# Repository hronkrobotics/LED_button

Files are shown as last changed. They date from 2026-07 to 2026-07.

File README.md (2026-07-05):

# LED Button

## Project Overview

This repository documents a modular ESP32-based LED button controller designed for rapid prototyping, debugging, and community experimentation. The project combines a custom PCB, modular JST-XH wiring, an OLED display, an 8x8 addressable LED matrix, mechanical switches, and a portable battery system into a compact handheld device.

The firmware in this repository remains the primary functional layer. This repository now adds the engineering documentation, mechanical references, PCB files, manufacturing notes, and assembly guidance required to build, service, and improve the hardware.

This platform is currently being used primarily as a VEX IQ STEM education curriculum asset, where it serves as an engaging hands-on tool for teaching timing, reaction, and interactive electronics concepts. It is also designed to be expandable into many other use cases, including outreach demonstrations, classroom competitions, prototyping platforms, and future connected or networked interactive systems.

## Demonstration Videos

These square-cropped demo clips are embedded directly in the README so they can play in the browser. The original source recordings are also preserved in [media/led-button-timer.mov](media/led-button-timer.mov) and [media/led-button-interface.mov](media/led-button-interface.mov).

### Timer mode
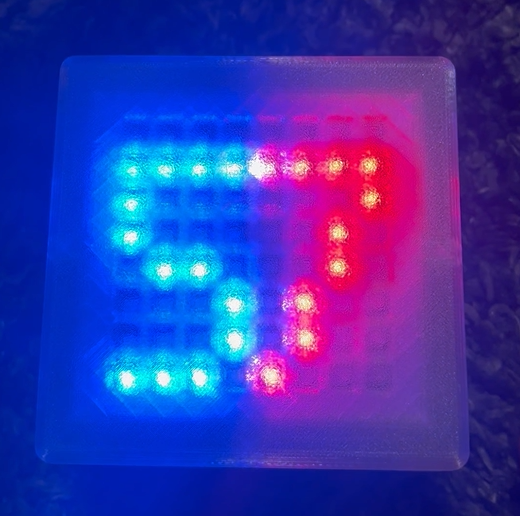
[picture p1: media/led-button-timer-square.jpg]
Timer mode preview


### Button mode
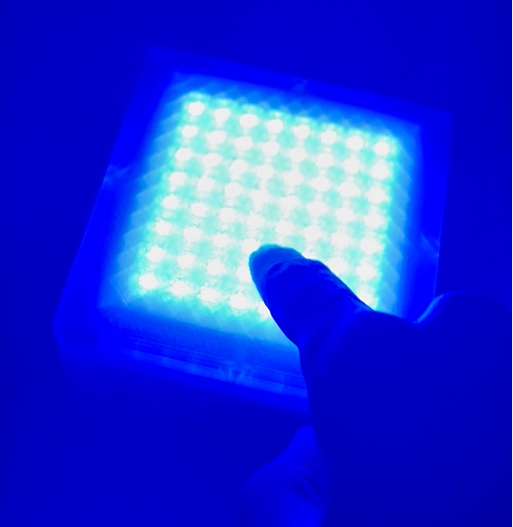
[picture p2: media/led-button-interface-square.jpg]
Button mode preview


## Features

- ESP32-based control platform
- 1.3-inch SH1106 OLED display
- 8x8 flexible WS2812B-compatible LED matrix
- Four Cherry MX Blue switches for primary input
- Two auxiliary momentary pushbuttons
- Passive piezo buzzer for audio feedback
- Dual 18650 battery system with external charging module
- Modular JST-XH connector architecture for easy assembly and replacement
- Firmware support for timer and reaction-style game modes

## Future UI and Connectivity Enhancements

Planned improvements for the next hardware and firmware iteration include:

- Wi-Fi connectivity for configuration, telemetry, and remote updates
- BLE support for phone or tablet pairing and control
- Multi-button serial connection for linking multiple units into a shared interactive setup

## Hardware Specifications

- Main controller: ESP32-WROOM-32
- Display: SH1106 OLED, 128x64
- LED matrix: 8x8 addressable LED panel
- Input: 4x Cherry MX Blue switches, 2x auxiliary buttons
- Power: 2x 18650 cells in a dual-cell holder/shield
- Charging: USB-C via external extension and battery shield
- Enclosure: 3D-printed housing with PCB standoffs and switch mounts

## Repository Structure

- [firmware](firmware/): firmware source and build assets
- [hardware](hardware/): PCB, CAD, manufacturing, and drawing files
- [docs](docs/): assembly, electronics, firmware, manufacturing, and add-on documentation
- [BOM](BOM/): bill of materials files and supporting documents

## Required Tools

- Arduino IDE or PlatformIO
- USB cable for firmware flashing
- Soldering iron and solder
- JST-XH crimping or soldering tools
- Hex drivers, screwdrivers, wire strippers, and flush cutters
- Multimeter for continuity and power testing

## Flashing Firmware

1. Open the firmware source in [firmware/LED_button.ino](firmware/LED_button.ino).
2. Select the appropriate ESP32 board profile in your toolchain.
3. Compile and upload the sketch.
4. Verify OLED initialization, button response, and LED output.

## Manufacturing and Assembly

See [docs/manufacturing/manufacturing-guide.md](docs/manufacturing/manufacturing-guide.md) for build instructions and [docs/assembly/assembly-guide.md](docs/assembly/assembly-guide.md) for mechanical assembly steps.

## License

This project is released under the MIT License. See [LICENSE](LICENSE) for details.

## Credits

- Firmware and prototype development: HRONK Robotics
- Hardware documentation and repository organization: HRONK Robotics
- Mechanical and electronic design references: included project files in this repository
- Wall-mount accessory reference: [hardware/cad/LED_BUTTON_VEX_WALL_MOUNT_3D_FILES.step](hardware/cad/LED_BUTTON_VEX_WALL_MOUNT_3D_FILES.step)

<!-- Add CAD renders, exploded views, and photographs here later -->

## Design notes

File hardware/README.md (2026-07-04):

# Hardware Overview

This folder stores the physical design assets for the LED button controller.

## Contents

- [pcb](pcb/): PCB schematic, manufacturing outputs, and connector information
- [cad](cad/): STEP files for the mechanical assemblies and enclosure components
- [stl](stl/): STL output location for printable parts
- [manufacturing](manufacturing/): build and fabrication notes
- [drawings](drawings/): drawing placeholders for future mechanical and assembly documentation

## Design Intent

The hardware revision documented here is a modular prototype platform. It prioritizes flexibility, serviceability, and rapid iteration over production optimization. The design intentionally uses an ESP32 development board, an external battery shield, and JST-XH wiring to simplify debugging and part replacement.

## Hardware Architecture

```mermaid
flowchart LR
    A[Battery pack] --> B[Battery shield / charger]
    B --> C[Power distribution]
    C --> D[ESP32 controller]
    C --> E[OLED display]
    C --> F[LED matrix]
    C --> G[Input buttons]
    C --> H[Buzzer]
    D --> E
    D --> F
    D --> G
    D --> H
```

This layout is chosen because it keeps the device portable and easy to service while still making the PCB the main integration point for the system. The split between modular subsystems and the custom PCB allows future revisions to improve manufacturing density without discarding the existing functional architecture.

## Included Files

- [pcb/LED_Button_PCB_Schematic.pdf](pcb/LED_Button_PCB_Schematic.pdf)
- [pcb/Gerber_LED_BUTTON_2026-07-04.zip](pcb/Gerber_LED_BUTTON_2026-07-04.zip)
- [cad/LED_BUTTON_3DFILES.step](cad/LED_BUTTON_3DFILES.step)
- [cad/LED_BUTTON_VEX_WALL_MOUNT_3D_FILES.step](cad/LED_BUTTON_VEX_WALL_MOUNT_3D_FILES.step)

<!-- Add CAD render or assembly photo here -->

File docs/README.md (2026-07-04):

# Documentation Index

This directory contains the engineering documentation for the LED button project.

## Documents

- [Assembly Guide](assembly/assembly-guide.md)
- [Electronics Overview](electronics/overview.md)
- [Firmware Overview](firmware/overview.md)
- [Manufacturing Guide](manufacturing/manufacturing-guide.md)
- [Add-ons](addons/walnut-addon.md)

The assembly workflow is documented as a single integrated assembly guide rather than separate mechanical and assembly documents.

## Related Resources

- [../README.md](../README.md)
- [../hardware/README.md](../hardware/README.md)
- [../BOM/README.md](../BOM/README.md)

<!-- Add system-level diagram or exploded view later -->

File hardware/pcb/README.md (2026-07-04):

# PCB Documentation

## Purpose

The custom PCB acts as the central interconnect platform for the LED button controller. It provides mechanical support for the ESP32 development board and routes power, ground, and GPIO signals to the OLED display, LED matrix, buttons, buzzer, and battery system.

## Design Notes

- The PCB is designed around modular JST-XH connectors.
- Power and ground are distributed to all subsystems through the PCB.
- The ESP32 development board is mounted as a removable module.
- The board is intended for debugging, prototype assembly, and easy maintenance.

## Key Interfaces

- OLED: I2C interface via JST connector
- LED matrix: single data line plus power and ground
- Switches: input lines with pull-ups in firmware
- Buzzer: PWM or simple digital output
- Battery shield: regulated 5 V power input

## Reference Files

- [LED_Button_PCB_Schematic.pdf](LED_Button_PCB_Schematic.pdf)
- [Gerber_LED_BUTTON_2026-07-04.zip](Gerber_LED_BUTTON_2026-07-04.zip)

## Placeholder Notes

- Connector pinout table to be expanded from the schematic once the final revision is verified.
- GPIO allocation table to be linked to the firmware mapping in [../docs/firmware/overview.md](../docs/firmware/overview.md).

<!-- Add PCB layout image or fabrication drawing here -->

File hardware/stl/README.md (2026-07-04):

# STL Files

This directory is reserved for exported STL files for the printable parts of the enclosure and accessories.

The current repository contains the source STEP files in [../cad](../cad). STL exports should be added here once prepared for fabrication.

<!-- Add STL exports and print notes here -->

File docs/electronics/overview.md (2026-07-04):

# Electronics Overview

## Hardware Architecture

The hardware is organized as a modular embedded system where power, sensing, actuation, and user interface functions are split into distinct blocks that connect through the custom PCB and JST-XH wiring.

```mermaid
flowchart LR
    A[2x 18650 cells] --> B[Battery shield / charger]
    B --> C[Regulated 5V rail]
    C --> D[ESP32-WROOM-32]
    C --> E[SH1106 OLED display]
    C --> F[8x8 LED matrix]
    C --> G[Cherry MX buttons]
    C --> H[Auxiliary buttons]
    C --> I[Passive buzzer]
    D --> E
    D --> F
    D --> G
    D --> H
    D --> I
    D --> J[Custom PCB + JST-XH connectors]
```

### Why These Design Choices Work

The hardware architecture favors rapid iteration and serviceability over maximum miniaturization:

- The ESP32 and battery shield are used as modular building blocks so the prototype can be reworked quickly.
- JST-XH connectors simplify assembly, debugging, and replacement of displays, LEDs, buttons, and power connections.
- The custom PCB centralizes the wiring and keeps the prototype easier to manufacture and test than a loose breadboard layout.
- The separate battery pack and charging path make the device portable without forcing the electronics to be permanently sealed into the enclosure.

## Main Components

### ESP32-WROOM-32
The ESP32 is the main controller for the device. It handles UI rendering, button scanning, LED animation, buzzer output, and high-level game logic.

### SH1106 OLED Display
The OLED display provides status information, menus, battery and mode information, and simple user feedback. It is connected over a 4-wire JST-XH interface using VCC, GND, SDA, and SCL.

### Flexible 8x8 LED Matrix
The LED matrix is used for visual output such as games, animations, and status cues. It is connected through a 3-wire JST-XH connector carrying 5 V, GND, and a single data line.

### Dual 18650 Battery System
The portable power source consists of two 18650 cells mounted in a battery holder or shield. The system powers the ESP32 and peripherals through a regulated 5 V output from the battery shield.

### Battery Shield and Charging
The battery shield serves as the power-management module. It provides battery charging, protection, and regulated output. The USB-C extension allows charging without opening the enclosure.

### Cherry MX Switches
The four Cherry MX Blue switches are the main input devices. Each switch interfaces as a simple active-low input to the ESP32. Firmware uses internal pull-ups.

### Auxiliary Pushbuttons
The two auxiliary momentary buttons are used for system functions such as start, select, reset, or mode switching.

### Passive Buzzer
The passive buzzer provides simple audio feedback for button presses, mode changes, game events, and alarms. The firmware drives it with PWM or timed tone output.

### Custom PCB
The PCB serves as the interconnect backbone for the entire device. It distributes power and routes signals between the ESP32 module and each peripheral connector.

## JST-XH Connectors

The following connector plan is documented for the prototype build:

| Connector | Destination | Purpose |
| --- | --- | --- |
| OLED JST | SH1106 OLED | Display power and I2C interface |
| LED JST | 8x8 LED matrix | Power and data |
| Button JST x4 | Cherry MX switches | Input lines |
| Aux JST x2 | Mechanical pushbuttons | System input |
| Buzzer JST | Passive buzzer | Audio output |
| Battery JST | Battery shield / power module | Regulated 5 V input |

## Cross References

- See [../firmware/overview.md](../firmware/overview.md) for firmware-side GPIO mapping.
- See [../../hardware/pcb/README.md](../../hardware/pcb/README.md) for PCB-level connector context.

<!-- Add connector pinout diagram or schematic cross-reference here -->

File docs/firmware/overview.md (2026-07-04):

# Firmware Overview

## Purpose

The firmware in this repository provides the functional behavior of the handheld button controller. The code is preserved as the primary product logic and is not rewritten here; instead, this document describes its role in the broader hardware system.

## Software Architecture

The firmware is a single-sketch, state-driven embedded application for the ESP32. Rather than using a full RTOS, it follows a lightweight cooperative loop in which the main program repeatedly reads input, updates game state, and refreshes the output devices. This keeps the implementation simple and easy to debug while still supporting the current timer and reaction-game behavior.

```mermaid
flowchart TD
    A[Input: control button + corner buttons] --> B[Debounce and decode]
    B --> C[State machine]
    C --> D[Timer mode subsystem]
    C --> E[Wack mode subsystem]
    D --> F[LED matrix renderer]
    E --> F
    D --> G[OLED UI updates]
    E --> G
    D --> H[Audio feedback]
    E --> H
    F --> I[User-visible output]
    G --> I
    H --> I
```

### Execution Model

The program is structured around a very simple control flow:

1. `setup()` initializes serial logging, GPIO pins, the LED matrix, the OLED display, and the initial menu state.
2. `loop()` runs continuously and performs three high-level tasks in order:
   - reads and debounces user input
   - updates the active mode state (timer or wack mode)
   - redraws the OLED screen and LED matrix when needed
3. A `needRedraw` flag is used to avoid unnecessary screen updates and keep the loop responsive.

This approach is well suited for a prototype because it is deterministic and easy to reason about, but it also makes the code structure highly centralized in the main sketch.

### Main Subsystems

#### 1. Input and Control Layer

The firmware reads two different input classes:

- the main control button for menu navigation and mode selection
- four corner buttons used in the wack-style interaction mode

The input handling layer uses GPIO with internal pull-up resistors and a debounce window to avoid false triggers when buttons are pressed or released. The control button also supports a short tap versus a hold, which is used to navigate menus and select modes.

#### 2. State Machine

The firmware operates around a small state machine defined by the `ScreenMode` enum:

- `MENU`: the main selection screen
- `MODE_TIMER`: the countdown timer experience
- `MODE_WACK`: the reaction-style color-change mode

This keeps the logic grouped by interaction mode and ensures that only the relevant subsystem is active at a given time.

#### 3. LED Matrix Rendering Layer

The LED matrix is driven through a pixel-addressing abstraction rather than direct raw writes. The firmware provides helper functions for:

- filling the full matrix with a single color
- placing a pixel at an $(x, y)$ coordinate using a serpentine mapping scheme
- animating a color spread from a chosen origin point

The wack mode uses this layer to create the visual spread effect that appears to originate from the corner or edge pressed by the user.

#### 4. Timer Subsystem

The timer mode uses a simple countdown model based on `millis()` rather than blocking delays. When the timer is entered:

- the countdown is initialized to 60 seconds
- a periodic tick updates the remaining time once per second
- the matrix is redrawn with large digit patterns for the countdown value
- the timer ends by triggering a finish effect and returning to the menu screen

This logic is intentionally lightweight, but it cleanly separates the timer behavior from the rest of the UI and input handling.

#### 5. Wack Mode Subsystem

The wack mode is the most interactive portion of the firmware. It reads a mask of which corner buttons are currently pressed, debounces the state, and then decides how to interpret that input. The system maps combinations of pressed corners to an origin point on the LED matrix and uses that origin to animate a new color spreading across the panel.

This provides the effect described in the project demo: the panel changes color and the spread appears to emerge from the corner or edge that was activated.

#### 6. Display and Feedback Layer

The OLED display is updated through the U8g2 library and is responsible for showing the menu, timer status, and mode instructions. The buzzer provides additional feedback for major actions such as entering a mode, changing color, and finishing the timer. This makes the device feel more responsive even when the visual state is changing.

### Data Flow

A typical event flow looks like this:

1. A button is pressed.
2. The input layer debounces the signal.
3. The active mode handler interprets the event.
4. The mode logic updates internal state, such as a countdown value or a new matrix animation.
5. The rendering layer updates the OLED display and LED matrix.
6. A tone may be played to confirm the action.

This structure keeps the firmware easy to follow and makes it straightforward to extend with new modes or features later.

### Design Notes

The current firmware prioritizes simplicity and clarity over modularity. That makes it ideal as a preserved prototype and a good base for future work. The main tradeoff is that most of the behavior remains centralized in one sketch file, so adding more advanced features such as Wi-Fi, BLE, or multi-device networking will benefit from breaking the logic into smaller modules.

### Why These Design Choices Work

The current architecture is intentionally straightforward:

- A cooperative main loop keeps the firmware deterministic and easy to follow for a prototype.
- A small state machine makes the timer and wack interactions explicit instead of scattering logic across the sketch.
- The LED matrix rendering layer isolates the physical panel mapping so the gameplay code can stay focused on behavior rather than pixel numbering.
- Direct GPIO-based input with debounce keeps the Bill of Materials and wiring simple while still being reliable enough for the current use case.

### Future Architectural Direction

As the project evolves, the same architecture can be expanded into a more modular design with:

- separate modules for input handling, display rendering, LED effects, and mode logic
- a small event queue for asynchronous actions and communication
- a clearer abstraction layer for future wireless features and multi-unit serial control

## GPIO Mapping

The current firmware uses the following general pin allocation:

| Function | GPIO |
| --- | --- |
| Control button | 23 |
| Top-left button | 27 |
| Bottom-left button | 26 |
| Top-right button | 33 |
| Bottom-right button | 32 |
| LED matrix data | 14 |
| Buzzer | 25 |
| OLED SCL | 21 |
| OLED SDA | 22 |

## Driver Notes

- OLED output is handled through the U8g2 library.
- LED effects are driven through the NeoPixel-compatible matrix interface.
- Buttons use input pull-up logic and debouncing.
- Audio feedback is implemented through simple tone output.

## Planned UI and Connectivity Enhancements

The next firmware iteration may add:

- Wi-Fi connectivity for configuration and telemetry
- BLE support for pairing with mobile devices
- Multi-button serial connection for coordinating multiple units

## Build and Flash

The main firmware source is [../../firmware/LED_button.ino](../../firmware/LED_button.ino).

1. Open the firmware file in Arduino IDE or PlatformIO.
2. Select the ESP32 board package.
3. Compile and upload the sketch.
4. Confirm display power, LED output, and button response.

## Power Considerations

The firmware assumes a stable regulated supply to the ESP32 and peripherals. Battery voltage should be verified before deployment.

<!-- Add firmware flow chart or state diagram later -->

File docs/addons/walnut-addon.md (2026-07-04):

# Wall-Mount Add-on

## Purpose

The wall-mount add-on is an optional accessory for the LED button platform. It is intended to allow the device to be installed on a wall or vertical surface as a display-style or interactive panel while preserving compatibility with the existing electronics.

## Reference Files

The wall-mount accessory is represented by the provided mechanical reference file:

- [hardware/cad/LED_BUTTON_VEX_WALL_MOUNT_3D_FILES.step](../../hardware/cad/LED_BUTTON_VEX_WALL_MOUNT_3D_FILES.step)

## Compatibility

- Compatible with the existing modular PCB and enclosure layout
- Intended for use with the current ESP32 firmware and button architecture
- Requires no change to core firmware behavior unless additional mounting or sensing features are introduced

## Installation

1. Confirm the wall-mount geometry is compatible with the current enclosure and mounting surface.
2. Install the mounting hardware and brackets using the specified fasteners.
3. Verify that switch travel, display clearance, and cable routing remain unobstructed.
4. Re-test the device after installation.

## Required Hardware

- Fasteners specified by the wall-mount design
- Mounting brackets or spacer hardware included with the accessory
- Appropriate wall anchors or screws for the target surface

## Firmware Compatibility

The base firmware should remain compatible. Additional firmware behavior should only be added if the mounting accessory introduces new sensing or actuation functions.

<!-- Add wall-mount render, exploded view, or installation photo later -->

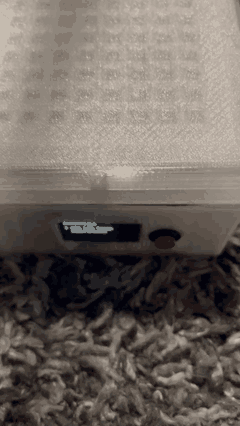
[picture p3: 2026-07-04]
media/led-button-timer.gif

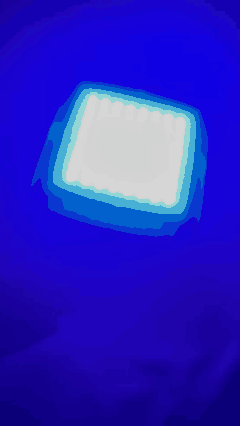
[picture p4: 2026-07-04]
media/led-button-interface.gif

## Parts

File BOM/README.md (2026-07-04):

# Bill of Materials

This folder contains the BOM files and related documentation for the PCB and prototype assembly.

## Included Files

- [BOM_LED_BUTTON_PCB_2026-07-04.xlsx](BOM_LED_BUTTON_PCB_2026-07-04.xlsx)
- [LED Button BOM - BOM.pdf](LED%20Button%20BOM%20-%20BOM.pdf)

## Categories

- Electronics
- PCB fabrication
- Hardware fasteners
- Printed components
- Mechanical assembly items

## Notes

The spreadsheet and PDF documents should be considered the authoritative source for procurement data. This repository provides the corresponding engineering context and cross-links to the assembly and manufacturing documentation.

<!-- Add supplier links and cost summary here -->

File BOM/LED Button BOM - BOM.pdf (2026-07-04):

## ELECTRONICS

Item No. | Part Name | Quantity | Unit Cost (CAD) | Replacement Link | Manufacturer Product Listing | Wire Length | Connector type | Manufacturing Notes
1 | SSH1106 1.3 in OLED | 1 | 3.53 | link (https://www.amazon.ca/HiLetgo-SSH1106-SSD1306-Display-Arduino/dp/B07BHHV844) | link (https://www.alibaba.com/product-detail/128x64-OLED-Display-SH1106-1-3_1600142946943.html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) | 120mm | 4 wires soldered -> 4 pins JST XH female | Ensure header configuration according to schematic
2 | Dual 18650 Battery Shield | 1 | 3.84 | link (https://www.amazon.ca/Lithium-Battery-Charging-Arduino-ESP8266/dp/B07SZKNST4?th=1) | link (https://www.alibaba.com/product-detail/Dual-18650-Lithium-Battery-Shield-V8_62005362345.html) | 100mm | 2 wires soldered -> 2 pins JST XH female | Ensure +/- header according to schematic, Cable to be soldered to 5v pinout on module
3 | EVE 18650 Lithium Ion Cell 3.7V 5000mah | 2 | 5.56 | link (https://www.amazon.ca/Svenirven-Battery-3-7V-Rechargeable-Button/dp/B0BPFC5XDD) | link (https://www.alibaba.com/product-detail/EVE-21700-3-6V-5000mah-3_1600900823356.html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) | N/A | N/A | N/A
4 | USB C Male to Female | 1 | 3.53 | link (https://www.amazon.ca/dp/B08HS6X44P?ref=ppx_yo2ov_dt_b_fed_asin_title) | link (https://www.alibaba.com/product-detail/100w-60w-Usb-c-Extension-Cables_1600833073068.html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) | 75mm | USBC Male -> USBC Female | Ensure cable length, 90 degree male connector would be preffered
5 | ESP32-Wroom-32 CP1202 30 Pin Dev Board | 1 | 3.53 | link (https://secure.sayal.com/STORE2/View_SHOP.php?SKU=260187) | link (https://www.alibaba.com/product-detail/ESP32S-Development-Board-with-WiFi-for_1601418080677.html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) | N/A | USB C INPUT female | Ensure USB C input
6 | Passive buzzer module (Piezoelectric, 3 pin) | 1 | 0.4 | link (https://www.amazon.ca/uxcell-Passive-Buzzer-Module-Piezoelectric/dp/B07R16YSBQ) | link (https://www.alibaba.com/product-detail/hot-sell-KY-006-Passive-Sensor_1601104536122.html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) | 50mm | 3 wire female dupont -> 3 wire JST XH | Ensure header configuration according to schematic
8 | 2750646 - PUSH SWITCH MOM 1P1T NO THR SOL 12.5MM 3A/125VAC 2 | | 0.32 | link (https://shop.sayal.com/products/scad-1451a?_pos=68&_sid=31e43084d&_ss=r) | link (https://www.alibaba.com/product-detail/12-5MM-Mounting-Hole-1A-250VAC_1601276976448.html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) | 100mm | 2 wires soldered -> 2 pin JST XH female | Header configuration does not matter
8 | Cherry MX Blue Mechanical Switch | 4 | 0.9028 | link (https://www.amazon.ca/dp/B0C6FH6XQ7?ref=ppx_yo2ov_dt_b_fed_asin_title) | link and link | 110mm | 2 wires soldered -> 2 pin JST XH female | Header configuration does not matter
9 | LED Matrix 8x8 Flexible | 1 | 2.47 | link (https://www.amazon.ca/dp/B08QN1XDWG?ref=ppx_yo2ov_dt_b_fed_asin_title) | link (https://www.alibaba.com/product-detail/Advertising-Ws2812b-Addressable-Led-Panel-Arduino_62238578715.html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) | 70mm and 30mmsolder->3 pin JST XH female | | Ensure JST XH header (NOT JST SM)
10 | PCB | 1 | 2 | link (https://jlcpcb.com/) | link (https://www.alibaba.com/product-detail/China-Custom-Low-Price-Original-Development_1601219646774.html) | N/A | ALL JST XH | Has its own manufacturing files which must be sent to manufacturer

HARDWARE - (washers and nuts just buy in bulk, all are m3) (per unit)
Size | Type | Size | Quanitity | Driver
M3 | Countersunk Bolt | 15mm | 4 | Hex
| | 20mm | 3 | Hex
| | 10mm | 2 | Hex
| screw | 5mm | 4 | Phillips

Hardware Cost ~ 1.5 CAD

3D printing cost ~ 7 CAD
Shipping ~ 5 CAD

UNIT Price = 39.58 CAD per unit

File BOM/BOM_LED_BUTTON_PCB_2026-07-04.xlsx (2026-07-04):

No. | Quantity | Comment | Designator | Footprint | Value | Manufacturer Part | Manufacturer | Supplier Part | Supplier | LCSC Price | LCSC Stock | JLCPCB Price | JLCPCB Stock
1 | 6 | B2B-XH-A(LF)(SN) | CN1,CN2,CN3,CN4,CN5,CN6 | CONN-TH_B2B-XH-A-LF-SN |  | B2B-XH-A(LF)(SN) | JST | C158012 | LCSC |  |  | 0.006 | 398456
2 | 2 | PM254-1-15-Z-8.5 | U12,U13 | HDR-TH_15P-P2.54-V-F |  | PM254-1-15-Z-8.5 | HCTL(华灿天禄) | C2897378 | LCSC |  |  | 0.0389 | 2361
3 | 2 | B3B-XH-A(LF)(SN) | U14,U16 | CONN-TH_3P-P2.50_A2501WV2-3P |  | B3B-XH-A(LF)(SN) | JST | C144394 | LCSC |  |  | 0.0081 | 215446
4 | 1 | B4B-XH-A(LF)(SN) | U15 | CONN-TH_B4B-XH-A-LF-SN |  | B4B-XH-A(LF)(SN) | JST | C144395 | LCSC |  |  | 0.0085 | 47137

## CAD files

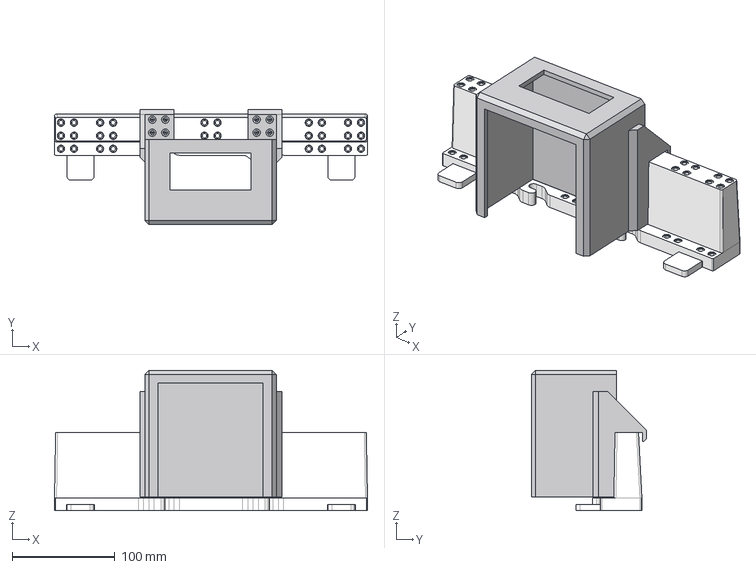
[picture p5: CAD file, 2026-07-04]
hardware/cad/LED_BUTTON_VEX_WALL_MOUNT_3D_FILES.step
304.7 x 112.4 x 136.5 mm

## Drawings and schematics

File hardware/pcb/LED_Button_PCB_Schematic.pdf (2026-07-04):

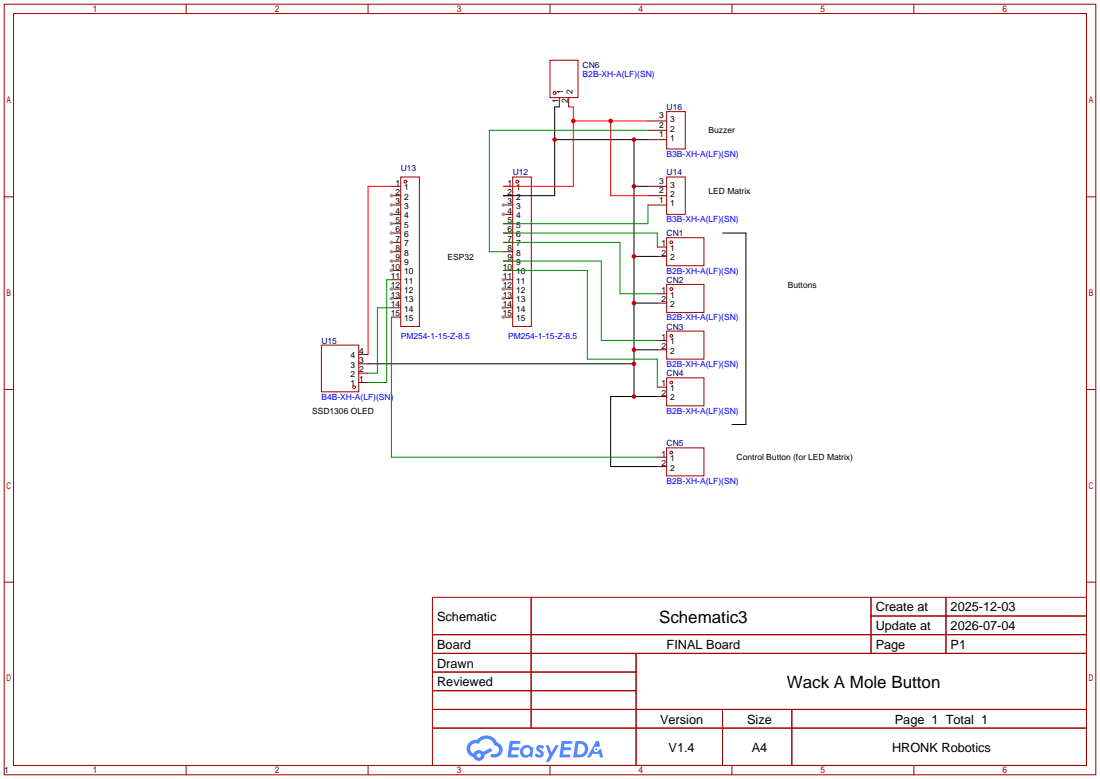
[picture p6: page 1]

Control Button (for LED Matrix)

Schematic | Schematic3 | Create at | 2025-12-03

Update at | 2026-07-04

Board | FINAL Board | Page | P1
Drawn | | Wack A Mole Button
Reviewed

Version | Size | Page 1 Total 1
V1.4 | A4 | HRONK Robotics

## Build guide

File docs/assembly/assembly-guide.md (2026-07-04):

# Assembly Guide

## Prototype Assembly Overview

This guide combines the mechanical and assembly workflow for the LED button controller into a single build document. It is intended for the modular prototype build and covers enclosure assembly, PCB installation, wiring, and final verification.

## Mechanical Assembly

1. Install the Cherry MX switches into the lid assembly.
2. Install the spacer behind the lid assembly.
3. Press the LED matrix holder into the switch subassembly.
4. Route the LED matrix cable through the designated openings.
5. Install the LED matrix into the holder.
6. Press-fit the diffuser cap over the LED matrix.
7. Verify smooth button travel.

## Main Body Assembly

1. Install the OLED display.
2. Install the auxiliary pushbuttons.
3. Install the battery holder or shield support.
4. Install the USB-C extension.
5. Assemble the PCB and mount the ESP32 module.
6. Connect all JST-XH connectors.
7. Remove the battery shield power switch if present and route external switch wires.
8. Mount the PCB into the enclosure.
9. Connect the OLED, LED matrix, buzzer, pushbuttons, and battery harnesses.
10. Install the batteries and close the enclosure.

## Final Checks

- All connectors seated correctly
- No pinched wires
- Buttons actuate smoothly
- LED matrix functions normally
- OLED initializes correctly
- USB charging works
- External power switch functions

<!-- Add exploded-view notes, photographs, or a single consolidated build sequence later -->

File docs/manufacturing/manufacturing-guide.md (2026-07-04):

# Manufacturing Guide

## Scope

This guide covers the prototype manufacturing workflow for the LED button controller. The design is intended as a modular, serviceable prototype rather than a highly optimized production design.

## Required Tools

- Soldering iron and solder
- JST-XH crimping or soldering tools
- Hex drivers
- Screwdrivers
- Flush cutters
- Wire strippers
- Multimeter

## PCB Manufacturing

- Use the provided Gerber archive in [../../hardware/pcb/Gerber_LED_BUTTON_2026-07-04.zip](../../hardware/pcb/Gerber_LED_BUTTON_2026-07-04.zip).
- Confirm board outline, copper layers, and drill files before fabrication.
- Review the schematic in [../../hardware/pcb/LED_Button_PCB_Schematic.pdf](../../hardware/pcb/LED_Button_PCB_Schematic.pdf).

## PCB Assembly

1. Populate the ESP32 footprint or mount the development board.
2. Install JST-XH headers and connectors.
3. Solder power and signal connections carefully.
4. Verify continuity between the PCB, battery shield, and peripherals.

## Cable Preparation

- Prepare JST-XH leads for the OLED, LED matrix, switches, buzzer, and battery module.
- Maintain consistent wire lengths and orientation.
- Label cables where possible to reduce assembly errors.

## Quality Checks

- Confirm no shorts between power and ground.
- Verify connector polarity and orientation.
- Confirm the OLED and LED matrix receive the correct supply rails.
- Validate button inputs and buzzer output after assembly.

## Prototype Design Philosophy

This repository represents the final modular prototype before a production-oriented revision. The design intentionally uses an ESP32 development board, an external battery module, JST-XH connectors, and modular wiring to maximize flexibility, debugging simplicity, and component replacement.

<!-- Add manufacturing checklist and process photos later -->

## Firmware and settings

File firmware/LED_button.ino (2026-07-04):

/****************************************************
 * HRONK Robotics Button Firmware - Version A
 *
 * Features:
 *  - Main menu (Timer Mode, Wack Mode)
 *  - 60s countdown timer displayed as big digits
 *      - 10–60: two digits (left=blue, right=red)
 *      - 0–9 : single centered digit (red)
 *  - Wack Mode:
 *      - Color = Red/Blue
 *      - Corner/edge button combos determine spread origin
 *      - Each press flips color (Red <-> Blue) with animation
 *  - Buzzer feedback (timer finish, color change)
 *  - OLED status displays for all modes
 *
 * Pin assignments:
 *  - CTRL_BTN (menu/select): GPIO 23
 *  - TL button: GPIO 27
 *  - BL button: GPIO 26
 *  - TR button: GPIO 33
 *  - BR button: GPIO 32
 *  - LED matrix DIN: GPIO 14
 *  - Buzzer: GPIO 25
 *  - OLED (software I2C): SCL=21, SDA=22
 ****************************************************/

#include <Adafruit_NeoPixel.h>
#include <U8g2lib.h>
#include <Wire.h>

//////////////////// OLED (SW I2C) ////////////////////////////

U8G2_SH1106_128X64_NONAME_F_SW_I2C u8g2(
  U8G2_R0,
  21,   // SCL
  22,   // SDA
  U8X8_PIN_NONE
);

//////////////////// CONTROL BUTTON (MENU) ////////////////////////////

#define CTRL_BTN 23
const unsigned long HOLD_MS     = 600;   // hold to select mode
const unsigned long DOUBLE_MS   = 300;   // double-tap to exit
const unsigned long DEBOUNCE_MS = 30;

unsigned long ctrlDownTime    = 0;
unsigned long lastCtrlTapTime = 0;
unsigned long lastDebounce    = 0;
bool ctrlWasDown              = false;
bool ctrlHoldTriggered        = false;
bool needRedraw               = true;

//////////////////// MODES ////////////////////////////

enum ScreenMode {
  MENU,
  MODE_TIMER,
  MODE_WACK
};

ScreenMode screen = MENU;
int menuIndex = 0;   // 0=Timer, 1=Wack mode

//////////////////// LED MATRIX & BUZZER ////////////////////////////

#define LED_PIN     14
#define LED_COUNT   64
#define BUZZER_PIN  25

Adafruit_NeoPixel matrix(LED_COUNT, LED_PIN, NEO_GRB + NEO_KHZ800);

// Colors
uint32_t RED()   { return matrix.Color(255, 0, 0); }
uint32_t BLUE()  { return matrix.Color(0, 80, 255); }  // boosted blue
uint32_t OFF()   { return matrix.Color(0, 0, 0); }

void fillMatrixColor(uint32_t c) {
  for (int i = 0; i < LED_COUNT; i++)
    matrix.setPixelColor(i, c);
  matrix.show();
}

//////////////////// MATRIX MAPPING (SERPENTINE) ////////////////////////////
// Matches your physical panel wiring

void setMatrixXY(int x, int y, uint32_t color) {
  if (x < 0 || x > 7 || y < 0 || y > 7) return;

  int idx;
  if (y % 2 == 0) {
    // even row: reversed (right → left)
    idx = y * 8 + (7 - x);
  } else {
    // odd row: normal (left → right)
    idx = y * 8 + x;
  }

  matrix.setPixelColor(idx, color);
}

//////////////////// BUZZER TONES ////////////////////////////

void redUpTone() {
  tone(BUZZER_PIN, 700, 90);  delay(100);
  tone(BUZZER_PIN, 900, 90);  delay(100);
  tone(BUZZER_PIN, 1200,120); delay(130);
}

void blueDownTone() {
  tone(BUZZER_PIN, 1200, 90); delay(100);
  tone(BUZZER_PIN, 900, 90);  delay(100);
  tone(BUZZER_PIN, 700,120);  delay(130);
}

void resetTone() {
  tone(BUZZER_PIN, 1000,80); delay(100);
  tone(BUZZER_PIN, 600,120); delay(130);
}

void timerFinishEffect() {
  for (int i = 0; i < 3; i++) {
    fillMatrixColor(RED());
    tone(BUZZER_PIN, 1200, 150);
    delay(200);
    fillMatrixColor(OFF());
    delay(200);
  }
}

//////////////////// WACK MODE BUTTONS ////////////////////////////
// Corners mapped as you specified:
// TL = 27, BL = 26, TR = 33, BR = 32

#define PIN_TL 27
#define PIN_BL 26
#define PIN_TR 33
#define PIN_BR 32

// Wack color state: 0=off, 1=red, 2=blue
int wackColorState = 0;

// Debouncing for wack buttons (mask-based)
const unsigned long WACK_DEBOUNCE_MS = 40;
uint8_t wackLastRawMask      = 0;
uint8_t wackDebouncedMask    = 0;
unsigned long wackLastChange = 0;

// Read corners into a 4-bit mask: bit0=TL, bit1=TR, bit2=BL, bit3=BR
uint8_t readWackButtonMaskRaw() {
  bool tl = (digitalRead(PIN_TL) == LOW);
  bool tr = (digitalRead(PIN_TR) == LOW);
  bool bl = (digitalRead(PIN_BL) == LOW);
  bool br = (digitalRead(PIN_BR) == LOW);

  uint8_t m = 0;
  if (tl) m |= 0x01;  // TL
  if (tr) m |= 0x02;  // TR
  if (bl) m |= 0x04;  // BL
  if (br) m |= 0x08;  // BR
  return m;
}

// Spread animation (diamond wave) from origin, painting newColor
void spreadFrom(int ox, int oy, uint32_t newColor) {
  // We DO NOT clear first; we progressively overwrite with newColor
  for (int r = 0; r <= 14; r++) {
    for (int y = 0; y < 8; y++) {
      for (int x = 0; x < 8; x++) {
        int dist = abs(x - ox) + abs(y - oy);
        if (dist <= r) {
          setMatrixXY(x, y, newColor);
        }
      }
    }
    matrix.show();
    delay(25);
  }
}

// Decide origin based on mask + paint next color
void handleWackSpread(uint8_t mask) {
  if (mask == 0) return; // no buttons pressed

  // Count how many pressed
  int count = 0;
  for (int i = 0; i < 4; i++) {
    if (mask & (1 << i)) count++;
  }

  int ox = 3;  // default origin = center
  int oy = 3;

  if (count == 1) {
    // Single corner
    if (mask & 0x01) { ox = 0; oy = 0; } // TL
    else if (mask & 0x02) { ox = 7; oy = 0; } // TR
    else if (mask & 0x04) { ox = 0; oy = 7; } // BL
    else if (mask & 0x08) { ox = 7; oy = 7; } // BR
  } else if (count == 2) {
    // Adjacent edges
    // TL + TR => top edge center
    if ((mask & 0x03) == 0x03) { ox = 3; oy = 0; }
    // BL + BR => bottom edge center
    else if ((mask & 0x0C) == 0x0C) { ox = 3; oy = 7; }
    // TL + BL => left edge center
    else if ((mask & 0x05) == 0x05) { ox = 0; oy = 3; }
    // TR + BR => right edge center
    else if ((mask & 0x0A) == 0x0A) { ox = 7; oy = 3; }
    else {
      // Diagonal pair => center
      ox = 3; oy = 3;
    }
  } else {
    // 3 or 4 buttons => center
    ox = 3; oy = 3;
  }

  // Decide next color (flip between red & blue)
  int newState;
  if (wackColorState == 0)      newState = 1; // start with red
  else                          newState = 3 - wackColorState; // 1<->2

  uint32_t newColor = (newState == 1) ? RED() : BLUE();

  // Run spread animation
  spreadFrom(ox, oy, newColor);

  // After animation, ensure entire matrix is that color
  fillMatrixColor(newColor);

  // Update global state + play tone
  wackColorState = newState;
  if (newState == 1) redUpTone();
  else               blueDownTone();
}

// Update Wack mode with debouncing
void updateWackMode() {
  uint8_t raw = readWackButtonMaskRaw();

  if (raw != wackLastRawMask) {
    wackLastRawMask = raw;
    wackLastChange  = millis();
  }

  if (millis() - wackLastChange >= WACK_DEBOUNCE_MS) {
    if (raw != wackDebouncedMask) {
      wackDebouncedMask = raw;

      // Only trigger on press combinations (ignore all-up)
      if (wackDebouncedMask != 0) {
        handleWackSpread(wackDebouncedMask);
      }
    }
  }
}

//////////////////// DIGIT BITMAP (4x7) FOR TIMER ////////////////////////////

const uint8_t digitBits[10][7][4] = {
  // 0
  {{0,1,1,0},{1,0,0,1},{1,0,0,1},{1,0,0,1},{1,0,0,1},{1,0,0,1},{0,1,1,0}},
  // 1
  {{0,0,1,0},{0,1,1,0},{1,0,1,0},{0,0,1,0},{0,0,1,0},{0,0,1,0},{1,1,1,1}},
  // 2
  {{0,1,1,0},{0,0,0,1},{0,0,0,1},{0,1,1,0},{1,0,0,0},{1,0,0,0},{1,1,1,1}},
  // 3
  {{0,1,1,0},{0,0,0,1},{0,0,0,1},{0,1,1,0},{0,0,0,1},{0,0,0,1},{0,1,1,0}},
  // 4
  {{1,0,0,1},{1,0,0,1},{1,0,0,1},{0,1,1,0},{0,0,0,1},{0,0,0,1},{0,0,0,1}},
  // 5
  {{1,1,1,1},{1,0,0,0},{1,0,0,0},{0,1,1,0},{0,0,0,1},{0,0,0,1},{1,1,1,0}},
  // 6
  {{0,1,1,0},{1,0,0,0},{1,0,0,0},{1,1,1,0},{1,0,0,1},{1,0,0,1},{0,1,1,0}},
  // 7
  {{1,1,1,1},{0,0,0,1},{0,0,1,0},{0,0,1,0},{0,1,0,0},{0,1,0,0},{1,0,0,0}},
  // 8
  {{0,1,1,0},{1,0,0,1},{1,0,0,1},{0,1,1,0},{1,0,0,1},{1,0,0,1},{0,1,1,0}},
  // 9
  {{0,1,1,0},{1,0,0,1},{1,0,0,1},{0,1,1,0},{0,0,0,1},{1,0,0,1},{0,1,1,0}}
};

// Draw a single digit at xOffset (0–3 for left, 4–7 for right, or 2–5 for centered)
void drawDigit(int digit, int xOffset, uint32_t color) {
  if (digit < 0 || digit > 9) return;

  for (int y = 0; y < 7; y++) {
    for (int x = 0; x < 4; x++) {
      if (digitBits[digit][y][x]) {
        setMatrixXY(x + xOffset, y + 1, color); // shift down one row
      }
    }
  }
}

// Draw the entire 2-digit countdown value
void drawCountdownDigits(int value) {
  if (value < 0) value = 0;
  if (value > 99) value = 99;

  // Clear matrix first
  fillMatrixColor(OFF());

  if (value >= 10) {
    int tens = value / 10;
    int ones = value % 10;
    drawDigit(tens, 0, BLUE());  // left digit (blue)
    drawDigit(ones, 4, RED());   // right digit (red)
  } else {
    drawDigit(value, 2, RED());  // centered single digit
  }

  matrix.show();
}

//////////////////// 60s TIMER LOGIC ////////////////////////////

bool timerActive      = false;
unsigned long nextTickMS = 0;
int timerRemaining    = 60;

void enterTimerMode() {
  screen = MODE_TIMER;
  timerActive     = true;
  timerRemaining  = 60;
  nextTickMS      = millis() + 1000;

  drawCountdownDigits(timerRemaining);
  needRedraw = true;
}

void updateTimerMode() {
  if (!timerActive) return;

  unsigned long now = millis();
  if (now >= nextTickMS) {
    nextTickMS += 1000;
    timerRemaining--;

    drawCountdownDigits(timerRemaining);
    needRedraw = true;

    if (timerRemaining <= 0) {
      timerActive = false;
      timerFinishEffect();
      fillMatrixColor(OFF());
      screen = MENU;
      needRedraw = true;
    }
  }
}

//////////////////// OLED SCREENS ////////////////////////////

void drawMenu() {
  u8g2.clearBuffer();
  u8g2.setFont(u8g2_font_6x10_tf);

  u8g2.drawStr(0,10,"HRONK Robotics");
  u8g2.drawStr(0,30, menuIndex==0 ? "> 60s LED Timer" : "  60s LED Timer");
  u8g2.drawStr(0,45, menuIndex==1 ? "> Wack-a-Mole"    : "  Wack-a-Mole");

  u8g2.sendBuffer();
}

void drawTimerScreen() {
  char buf[20];
  int remaining = timerRemaining;
  if (remaining < 0) remaining = 0;
  sprintf(buf,"Remaining: %2d", remaining);

  u8g2.clearBuffer();
  u8g2.setFont(u8g2_font_6x10_tf);
  u8g2.drawStr(0,10,"HRONK Robotics");
  u8g2.drawStr(0,25,"Digit LED Timer");
  u8g2.drawStr(0,40,buf);
  u8g2.drawStr(0,55,"Double-tap CTRL to exit");
  u8g2.sendBuffer();
}

void drawWackScreen() {
  u8g2.clearBuffer();
  u8g2.setFont(u8g2_font_6x10_tf);

  u8g2.drawStr(0,10,"HRONK Robotics");
  u8g2.drawStr(0,25,"Blue vs Red");
  u8g2.drawStr(0,40,"Hit button to start!");
  u8g2.drawStr(0,55,"Double-tap CTRL exit");

  u8g2.sendBuffer();
}

//////////////////// CONTROL BUTTON (MENU / MODES) ////////////////////////////

void handleControlButton() {
  bool raw = digitalRead(CTRL_BTN);

  if (millis() - lastDebounce < DEBOUNCE_MS) return;
  lastDebounce = millis();

  bool pressed = (raw == LOW);

  if (pressed && !ctrlWasDown) {
    ctrlDownTime = millis();
    ctrlHoldTriggered = false;
    ctrlWasDown = true;
  }

  // HOLD → select current menu mode
  if (pressed && ctrlWasDown && !ctrlHoldTriggered &&
      millis() - ctrlDownTime >= HOLD_MS) {

    ctrlHoldTriggered = true;

    if (screen == MENU) {
      if (menuIndex == 0) {
        enterTimerMode();
      } else {
        screen = MODE_WACK;
        wackColorState = 0;
        fillMatrixColor(OFF());
        needRedraw = true;
      }
    }
  }

  // RELEASE
  if (!pressed && ctrlWasDown) {
    unsigned long dur = millis() - ctrlDownTime;

    if (dur < HOLD_MS && !ctrlHoldTriggered) {
      // TAP
      if (screen == MENU) {
        menuIndex = (menuIndex + 1) % 2;
        needRedraw = true;
        lastCtrlTapTime = millis();
      } else {
        // check for double-tap exit
        if (millis() - lastCtrlTapTime < DOUBLE_MS) {
          screen = MENU;
          fillMatrixColor(OFF());
          timerActive    = false;
          wackColorState = 0;
          needRedraw     = true;
        }
        lastCtrlTapTime = millis();
      }
    }

    ctrlWasDown = false;
  }
}

//////////////////// SETUP ////////////////////////////

void setup() {
  Serial.begin(115200);

  pinMode(CTRL_BTN, INPUT_PULLUP);

  pinMode(PIN_TL, INPUT_PULLUP);
  pinMode(PIN_TR, INPUT_PULLUP);
  pinMode(PIN_BL, INPUT_PULLUP);
  pinMode(PIN_BR, INPUT_PULLUP);

  pinMode(BUZZER_PIN, OUTPUT);

  matrix.begin();
  matrix.setBrightness(64);
  fillMatrixColor(OFF());

  u8g2.begin();
  drawMenu();
  needRedraw = false;

  randomSeed(esp_random());
}

//////////////////// MAIN LOOP ////////////////////////////

void loop() {
  handleControlButton();

  if (screen == MODE_TIMER)
    updateTimerMode();
  else if (screen == MODE_WACK)
    updateWackMode();

  if (needRedraw) {
    needRedraw = false;

    if      (screen == MENU)       drawMenu();
    else if (screen == MODE_TIMER) drawTimerScreen();
    else if (screen == MODE_WACK)  drawWackScreen();
  }
}

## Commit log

2026-07-04 HRONK Robotics LED Button Firmware - Version A
2026-07-04 Add hardware documentation and repository structure
    [BOM_LED_BUTTON_PCB_2026-07-04.xlsx, LED_BUTTON_VEX_WALL_MOUNT_3D_FILES.step]
2026-07-04 Clarify wall-mount add-on documentation
2026-07-04 Consolidate assembly and mechanical guidance
2026-07-05 Switch README video embeds to raw GitHub URLs
2026-07-05 Clarify VEX IQ curriculum use case in README
